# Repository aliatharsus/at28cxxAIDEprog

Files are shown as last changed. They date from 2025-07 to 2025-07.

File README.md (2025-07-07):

# AT28cXXX EEPROM Programmer - ArduinoIDE + WebApp

No bloated libraries, no dependencies, no nonsense.  
Just plug your EEPROM into any Arduino-compatible board, open a browser, and flash/read/fill with ease.

Supports **AT28C64**, **AT28C128**, **AT28C256**  
Only `.bin` files for now.

ADDED .org (* = $xxxx) support

---

## Features

-  Write `.bin` files to EEPROM (AT28C64 / 128 / 256)
-  Read EEPROM to browser (in nice hex format)
-  Fill EEPROM with any byte (default = EA)
-  Write a byte to specific address
-  Read a byte from specific address
-  Pure browser interface (no Python, no CLI tools)
-  Blinks pin 2 every 256 bytes for visual progress
-  Easy wiring via 2x 74HC595 shift registers for address bus

---

##  Known Issues

- **Read operation freezes browser UI**  
  Not a bug. It's just flooding serial data. The browser *will* show everything after it finishes. Be patient.

- **No verify after write**  
  If you need it, feel free to add a read loop — the code is totally open.

---

## Setup

### Hardware

- EEPROM: AT28C64 / 128 / 256 (28-pin DIP)
- 2x 74HC595 shift registers for 16-bit addressing (actually 15 for c256)
- Data lines go to any 8 GPIOs
- Wire everything as per your board and change the pin numbers at the top of the `.ino` file, and upload (an example with nodemcu32s esp32 board is provided in the png)

```cpp
const int dataPins[8] = {23, 22, 16, 32, 33, 25, 26, 27};
#define STCP 21
#define SHCP 19
#define SRDT 17
#define WE 14
#define OE 13

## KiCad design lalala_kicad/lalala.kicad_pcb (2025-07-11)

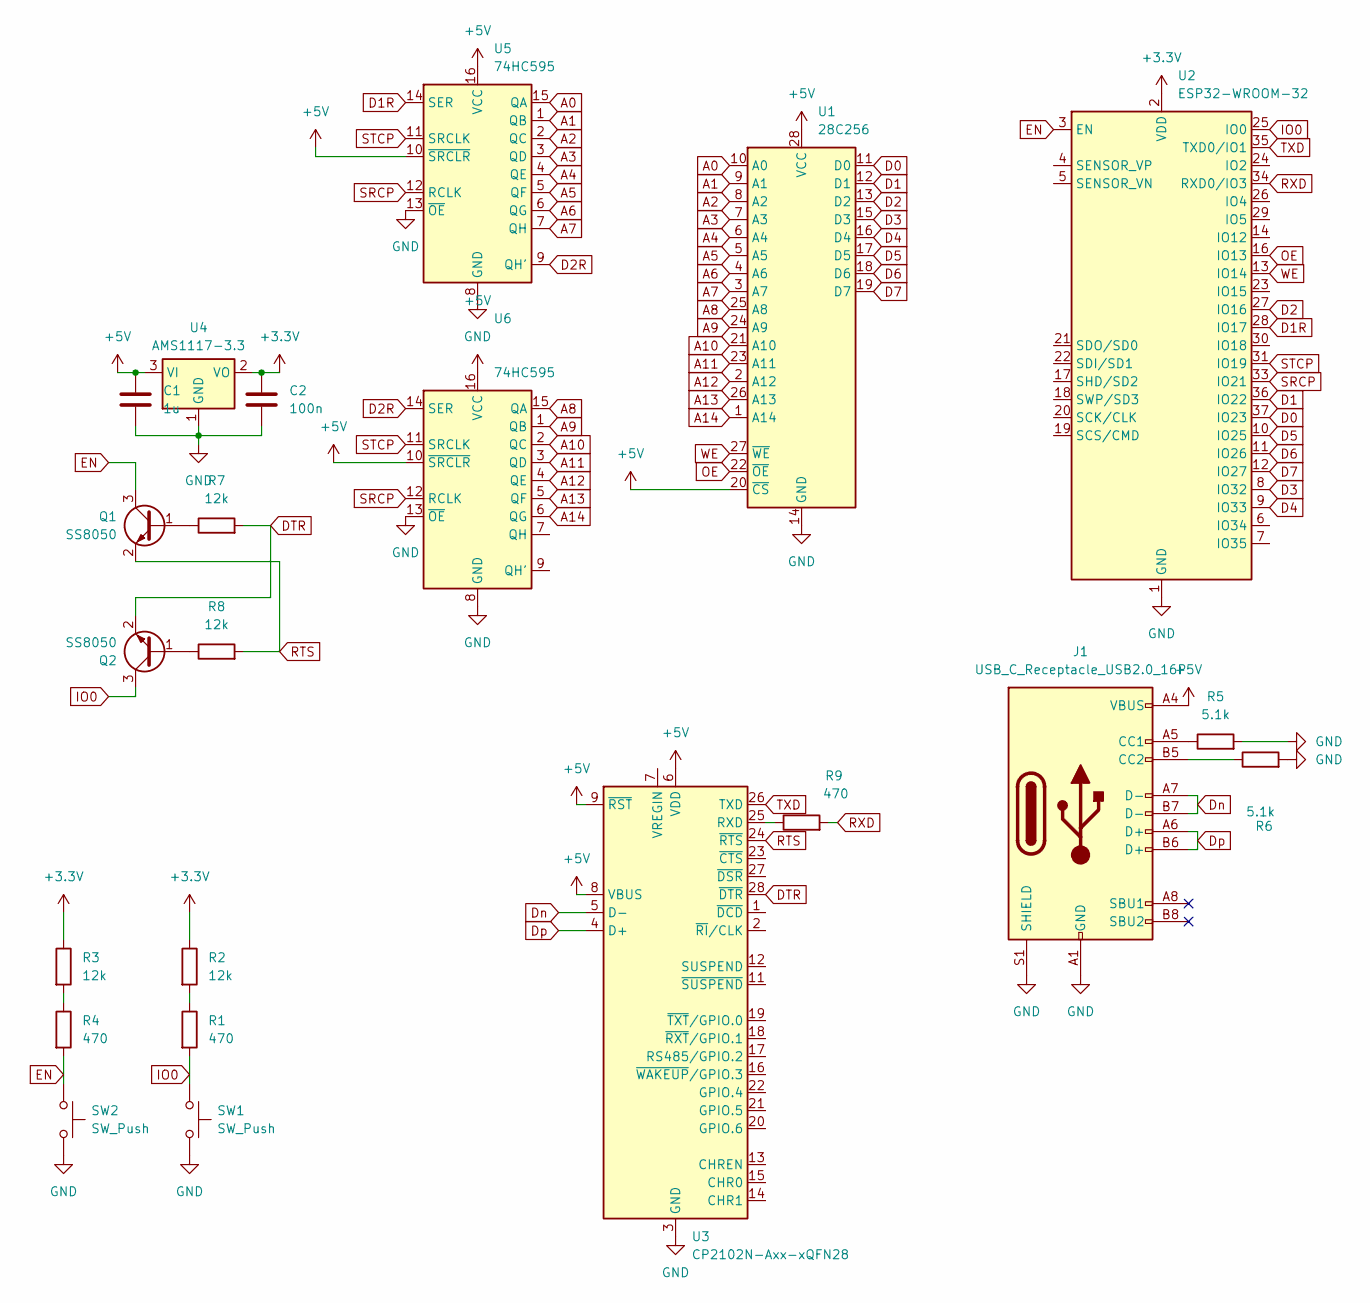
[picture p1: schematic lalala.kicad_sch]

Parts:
C1: 1u; C_0805_2012Metric
C2: 100n; C_0805_2012Metric
J1: USB_C_Receptacle_USB2.0_16P; USB_C_Receptacle_GCT_USB4105-xx-A_16P_TopMnt_Horizontal
Q1, Q2: SS8050; SOT-23
R1, R4, R9: 470; R_0805_2012Metric
R2, R3, R7, R8: 12k; R_0805_2012Metric
R5, R6: 5.1k; R_0805_2012Metric
SW1, SW2: SW_Push; SW_SPST_TL3342
U1: 28C256; DIP-28_W15.24mm_LongPads
U2: ESP32-WROOM-32
U3: CP2102N-Axx-xQFN28; QFN-28-1EP_5x5mm_P0.5mm_EP3.35x3.35mm
U4: AMS1117-3.3; SOT-223-3_TabPin2
U5, U6: 74HC595; DIP-16_W7.62mm_LongPads

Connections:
+3.3V: C2.1, R2.1, R3.1, U2.2 (VDD), U4.2 (VO)
+5V: C1.1, J1.A4 (VBUS), J1.A9 (VBUS), J1.B4 (VBUS), J1.B9 (VBUS), U1.20 (~CS), U1.28 (VCC), U3.6 (VDD), U3.8 (VBUS), U3.9 (~RST), U4.3 (VI), U5.10 (~SRCLR), U5.16 (VCC), U6.10 (~SRCLR), U6.16 (VCC)
A0: U1.10 (A0), U5.15 (QA)
A1: U1.9 (A1), U5.1 (QB)
A2: U1.8 (A2), U5.2 (QC)
A3: U1.7 (A3), U5.3 (QD)
A4: U1.6 (A4), U5.4 (QE)
A5: U1.5 (A5), U5.5 (QF)
A6: U1.4 (A6), U5.6 (QG)
A7: U1.3 (A7), U5.7 (QH)
A8: U1.25 (A8), U6.15 (QA)
A9: U1.24 (A9), U6.1 (QB)
A10: U1.21 (A10), U6.2 (QC)
A11: U1.23 (A11), U6.3 (QD)
A12: U1.2 (A12), U6.4 (QE)
A13: U1.26 (A13), U6.5 (QF)
A14: U1.1 (A14), U6.6 (QG)
D0: U1.11 (D0), U2.37 (IO23)
D1: U1.12 (D1), U2.36 (IO22)
D1R: U2.28 (IO17), U5.14 (SER)
D2: U1.13 (D2), U2.27 (IO16)
D2R: U5.9 (QH'), U6.14 (SER)
D3: U1.15 (D3), U2.8 (IO32)
D4: U1.16 (D4), U2.9 (IO33)
D5: U1.17 (D5), U2.10 (IO25)
D6: U1.18 (D6), U2.11 (IO26)
D7: U1.19 (D7), U2.12 (IO27)
DTR: Q2.2 (E), R7.2, U3.28 (~DTR)
Dn: J1.A7 (D-), J1.B7 (D-), U3.5 (D-)
Dp: J1.A6 (D+), J1.B6 (D+), U3.4 (D+)
EN: Q1.3 (C), R4.2, SW2.1, U2.3 (EN)
GND: C1.2, C2.2, J1.A1 (GND), J1.A12 (GND), J1.B1 (GND), J1.B12 (GND), J1.S1 (SHIELD), R5.2, R6.2, SW1.2, SW2.2, U1.14 (GND), U2.1 (GND), U2.15 (GND), U2.38 (GND), U2.39 (GND), U3.3 (GND), U3.29 (GND), U4.1 (GND), U5.8 (GND), U5.13 (~OE), U6.8 (GND), U6.13 (~OE)
IO0: Q2.3 (C), R1.2, SW1.1, U2.25 (IO0)
unnamed: J1.A5 (CC1), R5.1
unnamed: J1.B5 (CC2), R6.1
unnamed: Q1.1 (B), R7.1
unnamed: Q2.1 (B), R8.1
unnamed: R1.1, R2.2
unnamed: R3.2, R4.1
unnamed: R9.1, U3.25 (RXD)
OE: U1.22 (~OE), U2.16 (IO13)
RTS: Q1.2 (E), R8.2, U3.24 (~RTS)
RXD: R9.2, U2.34 (RXD0/IO3)
SRCP: U2.33 (IO21), U5.12 (RCLK), U6.12 (RCLK)
STCP: U2.31 (IO19), U5.11 (SRCLK), U6.11 (SRCLK)
TXD: U2.35 (TXD0/IO1), U3.26 (TXD)
WE: U1.27 (~WE), U2.13 (IO14)

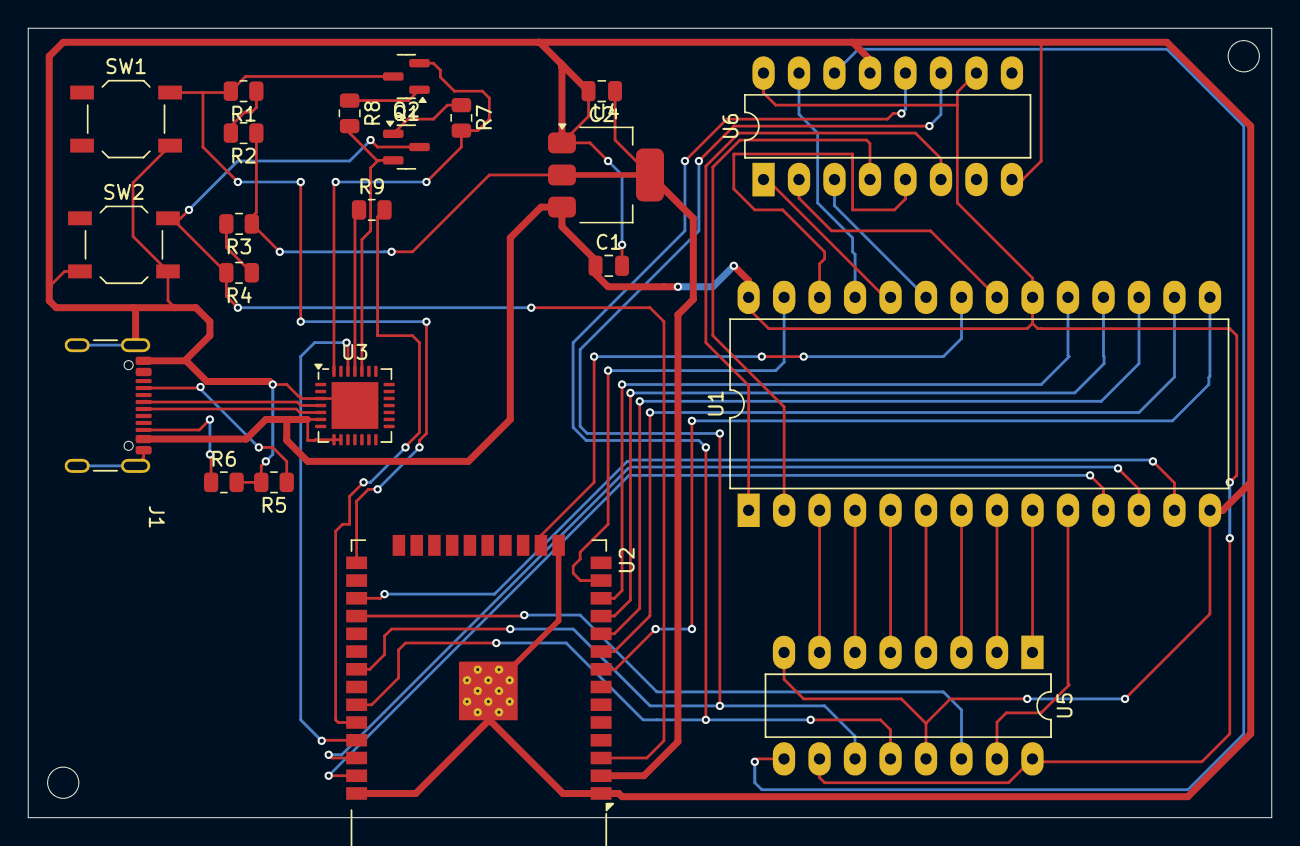
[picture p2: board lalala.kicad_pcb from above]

Board: 2 copper layers, 89.0 x 56.5 mm, 22 parts (0 on the bottom side), 47 nets.

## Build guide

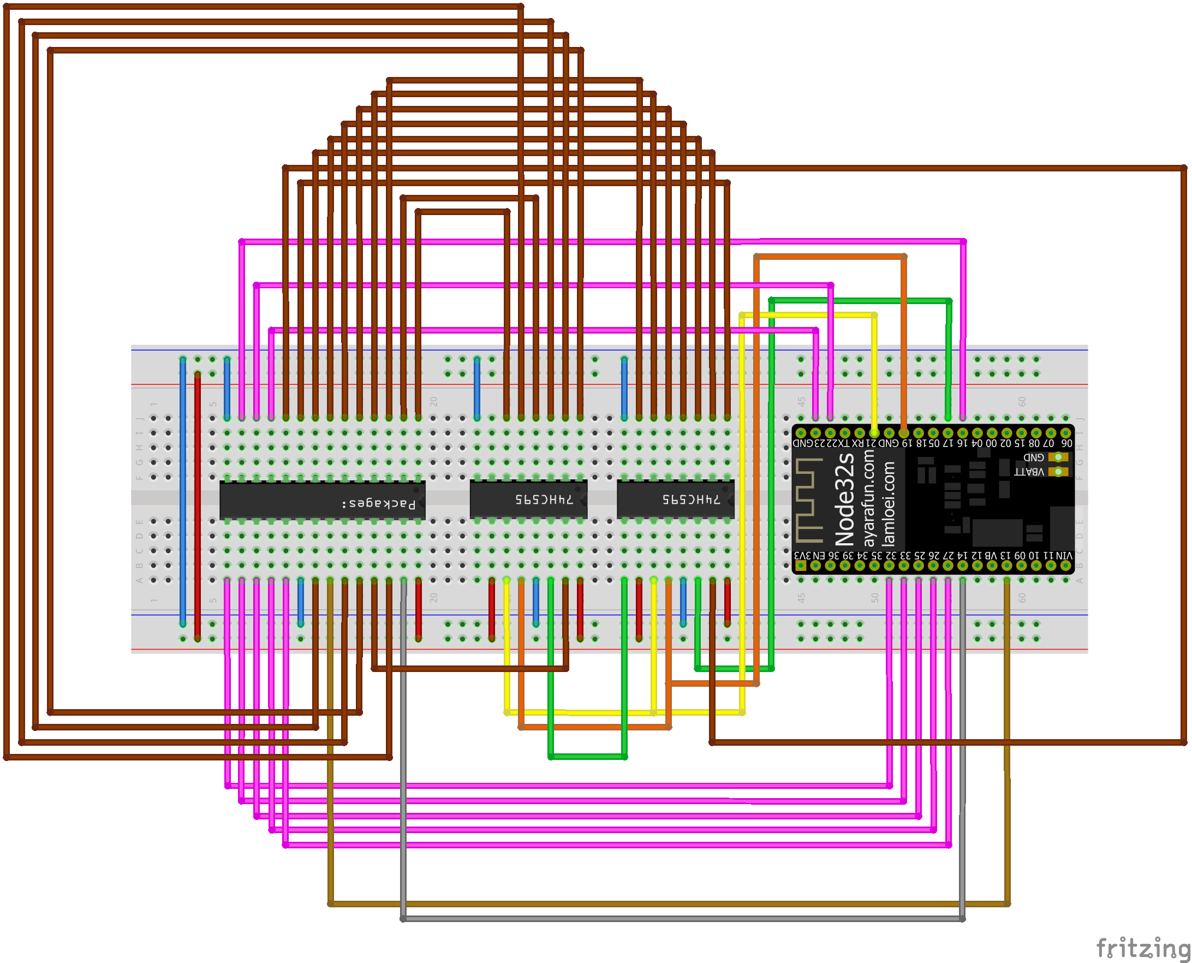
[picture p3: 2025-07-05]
wiring.png

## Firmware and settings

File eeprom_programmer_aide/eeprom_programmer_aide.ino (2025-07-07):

const int dataPins[8] = {23, 22, 16, 32, 33, 25, 26, 27};

#define STCP 21
#define SHCP 19
#define SRDT 17

#define WE 14
#define OE 13

#define READ 1
#define WRITE 0

#define AT28C64 8192
#define AT28C256 32768

enum Mode { IDLE, ORG_WAIT, WRITING, READING, FILLING, ADWRITING, ADREADING };
Mode mode = IDLE;
uint16_t romSize = AT28C64;
uint16_t addr = 0;
String input = "";

bool fillFlag=0;
byte filler=0xEA;

bool noOrg=0;
bool writeFlagOrg=0;

bool adwriteFlag=0;

unsigned long lastWriteTime = 0;
const unsigned long writeTimeout = 6000;

void setup() {
  Serial.begin(9600);
  
  pinMode(STCP, OUTPUT);
  pinMode(SHCP, OUTPUT);
  pinMode(SRDT, OUTPUT);
  pinMode(WE, OUTPUT);
  pinMode(OE, OUTPUT);
  pinMode(2, OUTPUT); digitalWrite(2, LOW);

  digitalWrite(STCP, LOW);
  digitalWrite(SHCP, LOW);
  digitalWrite(SRDT, LOW);
  digitalWrite(OE, HIGH);
  digitalWrite(WE, HIGH);
  dataConfig(READ);
}

void loop() {
  //For auto debug message print
  /*
  static unsigned long lastDebug = 0;   //debug every 2 sec
  if (millis() - lastDebug > 2000 && mode!=READING) {
    Serial.print("DEBUG: Mode=");
    Serial.print(mode);
    Serial.print(" Addr=");
    Serial.print(addr);
    Serial.print(" Input='");
    Serial.print(input);
    Serial.println("'");
    lastDebug = millis();
  }*/


  if (mode == IDLE) {
    while (Serial.available()) {
      char c = Serial.read();
      //for per symbol debugging
      /*
      Serial.print("DEBUG: Got char: '");
      Serial.print(c);
      Serial.print("' (");
      Serial.print((int)c);
      Serial.println(")");
      */
      
      if (c == '\n' || c == '\r') {
        Serial.print("Processing command: '");
        Serial.print(input);
        Serial.println("'");
        
        if (input.startsWith("WRITE:")) {
          romSize = input.substring(6).toInt();
          Serial.print("Extracted romSize: ");
          Serial.println(romSize);
          if (romSize == 8192 || romSize == 32768 || romSize == 16384) {
            dataConfig(WRITE);
            addr=0;
            mode = ORG_WAIT;
            Serial.println("WAITING_FOR_ORG");
            lastWriteTime = millis();
          } else {
            Serial.print("ERROR: Invalid romSize: ");
            Serial.println(romSize);
          }
        } 
        else if (input.startsWith("READ:")) {
          romSize = input.substring(5).toInt();
          addr = 0;
          dataConfig(READ);
          mode = READING;
          Serial.println("READING_STARTED");
        }
        else if (input.startsWith("FILL:")) {
          romSize = input.substring(5).toInt();
          addr = 0;
          dataConfig(WRITE);
          mode = FILLING;
          Serial.println("Filling...");
        }
        else if (input.startsWith("ADWR:")) {
          romSize = input.substring(5).toInt();
          addr = 0;
          dataConfig(WRITE);
          mode = ADWRITING;
        }
        else if (input.startsWith("ADRD:")) {
          romSize = input.substring(5).toInt();
          addr = 0;
          dataConfig(READ);
          mode = ADREADING;
        }
        else if (input.startsWith("DEBUG")) {
          Serial.print("DEBUG: Mode=");
          Serial.print(mode);
          Serial.print(" Addr=");
          Serial.print(addr);
          Serial.print(" Input='");
          Serial.print(input);
          Serial.println("'");
        }
        else if (input.length() > 0) {
          Serial.print("ERROR: Unknown command: '");
          Serial.print(input);
          Serial.println("'");
        }
        
        input = "";
        break;
      } else if (c >= 32 && c <= 126) {
        input += c;
      }
    }
  }
    if (mode == ORG_WAIT) {
    if (Serial.available() >= 2) {
      uint8_t low = Serial.read();
      uint8_t high = Serial.read();
      addr = low | (high << 8);
      lastWriteTime = millis();
      mode = WRITING;
      Serial.print("ORG_SET: ");
      Serial.println(addr, HEX);
    } else {
      if (millis() - lastWriteTime > 3000) {
        Serial.println("ORG_TIMEOUT, writing at 0x0000");
        addr = 0;
        mode = WRITING;
      }
    }
  }

  if (mode == WRITING) {
  if (Serial.available()) {
    uint8_t byte = Serial.read();
    lastWriteTime = millis();

    Serial.print(addr, HEX);
    Serial.print(" : ");
    Serial.println(byte, HEX);

    if (addr < romSize) {
      writeByte(addr, byte);
      addr++;
    } else {
      Serial.println("ERROR: Addr exceeds ROM size");
      mode = IDLE;
      dataConfig(READ);
    }
  } else if (millis() - lastWriteTime > writeTimeout) {
    Serial.println("WRITE_TIMEOUT");
    mode = IDLE;
    dataConfig(READ);
  }
}

  if (mode == READING) {
    const uint8_t bytesPerLine = 8;

    if (addr < romSize) {
      if (addr % bytesPerLine == 0) {
        Serial.print("0x");
        if (addr < 0x1000) Serial.print("0");
        if (addr < 0x0100) Serial.print("0");
        if (addr < 0x0010) Serial.print("0");
        Serial.print(addr, HEX);
        Serial.print(": ");
      }

      uint8_t b = readByte(addr++);
      if (b < 0x10) Serial.print("0");
      Serial.print(b, HEX);
      Serial.print(" ");

      if (addr % bytesPerLine == 0) Serial.println();
      //if (addr % 256 == 0) digitalWrite(2, !digitalRead(2));
    } else {
      Serial.println();
      Serial.println("READ_COMPLETE");
      mode = IDLE;
    }
  }
  if (mode == FILLING) {
    if(addr<romSize){
      if(Serial.available() && !fillFlag){filler = Serial.read(); fillFlag=1;Serial.print("FILL_BYTE: 0x");Serial.println(filler, HEX);}
      if(fillFlag){
        writeByte(addr,filler);
        addr++;
      }
    }
    else{
      addr = 0;
      mode = IDLE;
      filler = 0xEA;
      fillFlag = 0;
      Serial.println("Fill Complete");
    }
  }
if (mode == ADWRITING) {
  static byte adwriteByte = 0;
  if (!adwriteFlag && Serial.available() >= 3) {
    uint8_t low = Serial.read();
    uint8_t high = Serial.read();
    addr = low | (high << 8);
    adwriteByte = Serial.read();
    adwriteFlag = 1;
  }

  if (adwriteFlag) {
    adwriteFlag = 0;
    writeByte(addr, adwriteByte);
    addr = 0;
    mode = IDLE;
    Serial.println("Written");
  }
}
if (mode == ADREADING) {
  if (Serial.available() >= 2) {
    uint8_t low = Serial.read();
    uint8_t high = Serial.read();
    addr = low | (high << 8);
    byte adreadByte=readByte(addr);
    mode = IDLE;
    Serial.print("Data at ");
    Serial.print(addr,HEX);
    Serial.print(" : ");
    Serial.println(adreadByte,HEX);
    addr = 0;
  }
}

if(mode==IDLE){
  digitalWrite(2,HIGH);
}
else{
  if(addr%256==0){
    digitalWrite(2,!digitalRead(2));
  }
}

}

void writeByte(uint16_t addr, byte dattt) {
  shiftOut16(addr);
  dataOut(dattt);
  digitalWrite(WE, LOW);
  asm volatile("nop\n\t"
               "nop\n\t");
  digitalWrite(WE, HIGH);
  delay(10);
}

uint8_t readByte(uint16_t addr) {
  digitalWrite(OE, HIGH);
  delayMicroseconds(15);
  shiftOut16(addr);
  delayMicroseconds(15);
  digitalWrite(OE, LOW);
  delayMicroseconds(50);
  return dataRead();
}

void shiftOut16(uint16_t data) {
  shiftOut(SRDT, SHCP, MSBFIRST, (data >> 8) & 0xFF);
  shiftOut(SRDT, SHCP, MSBFIRST, data & 0xFF);

  delayMicroseconds(1);
  digitalWrite(STCP, HIGH);
  delayMicroseconds(10);
  digitalWrite(STCP, LOW);
  delayMicroseconds(5);
}

void dataOut(uint8_t data) {
  for (int i = 0; i < 8; i++) {
    digitalWrite(dataPins[i], (data >> i) & 0x01);
  }
}

uint8_t dataRead() {
  delayMicroseconds(1);
  uint8_t value = 0;
  for (int i = 0; i < 8; i++) {
    value |= (digitalRead(dataPins[i]) << i);
  }
  return value;
}

void dataConfig(bool state) {
  if (state) {
    for (int i = 0; i < 8; i++) {
      pinMode(dataPins[i], INPUT);
      digitalWrite(dataPins[i], LOW);
    }
    digitalWrite(OE, LOW);
  }
  else {
    for (int i = 0; i < 8; i++) {
      pinMode(dataPins[i], OUTPUT);
      digitalWrite(dataPins[i], LOW);
    }
    digitalWrite(OE, HIGH);
  }
}
